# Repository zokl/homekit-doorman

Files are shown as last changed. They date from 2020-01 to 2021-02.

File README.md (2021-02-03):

# Doorman HomeKit System
System of a doorbell and smart lock integration into Apple HomeKit. The project platform is ESP8266 - [WeMos D1 Mini](https://wiki.wemos.cc/products:d1:d1_mini). Target door phone system is [Fermax](https://github.com/zokl/homekit-doorman/blob/master/doc/Fermax%20CityMax%20Universal%20%20Intercom%20Handset%20Data%20Sheet.pdf).

The SW part of the project is based on https://github.com/maximkulkin/esp-homekit-demo and https://github.com/pfalcon/esp-open-sdk.

## Fermax phone interconnection

Fermax phone signals:
* **RingDet** - ringing detector
   * **3** - common (- on PCB)
   * **4** - call (+ on PCB)
* **Lock** - door lock control
   * **1** - door opener and microphone supply (+ on PCB)
   * **3** - common (+ on PCB)

## Initial configuration

The initial configuration could be modified in the file [config.h](https://github.com/zokl/homekit-doorman/blob/master/src/config.h).

### HomeKit Access Parameters

* HOMEKIT_PASSWORD - "111-00-111"
* HOMEKIT_SETUP_ID - "1QJ9"

### System Parameters

* The GPIO pin that is connected to a relay - WeMos D1 Mini - Pin D1
* The GPIO pin that is connected to a LED - WeMos D1 Mini - Pin D4 (Internal Blue LED)
* The GPIO pin that is connected to a button - WeMos D1 Mini - Pin D3
  * Button for door open or factory reset
* The GPIO pin that is connected to a door bell - WeMos D1 Mini - Pin D2
  * Door bell detection - iOS notify as moving
* Timeout in seconds to open lock for - 5 seconds
* Button timeout for log press - 10000 ms (factory reset)
  * Shorter press = open the door
* Doorbell notify timeout - 3000 ms
  * After this timeout system disarm the door bell notification

## PCB Design

PCB is designed for using in DIN rail box [Z103J ABS V0 KRADEX](https://github.com/zokl/homekit-doorman/blob/master/doc/dsh.627-099.1.pdf) with AC/DC power supply [MEAN WELL DR-15-5](https://github.com/zokl/homekit-doorman/blob/master/doc/dsh.751-263.1.pdf). **The system can be powered only by 5V DC!!!**

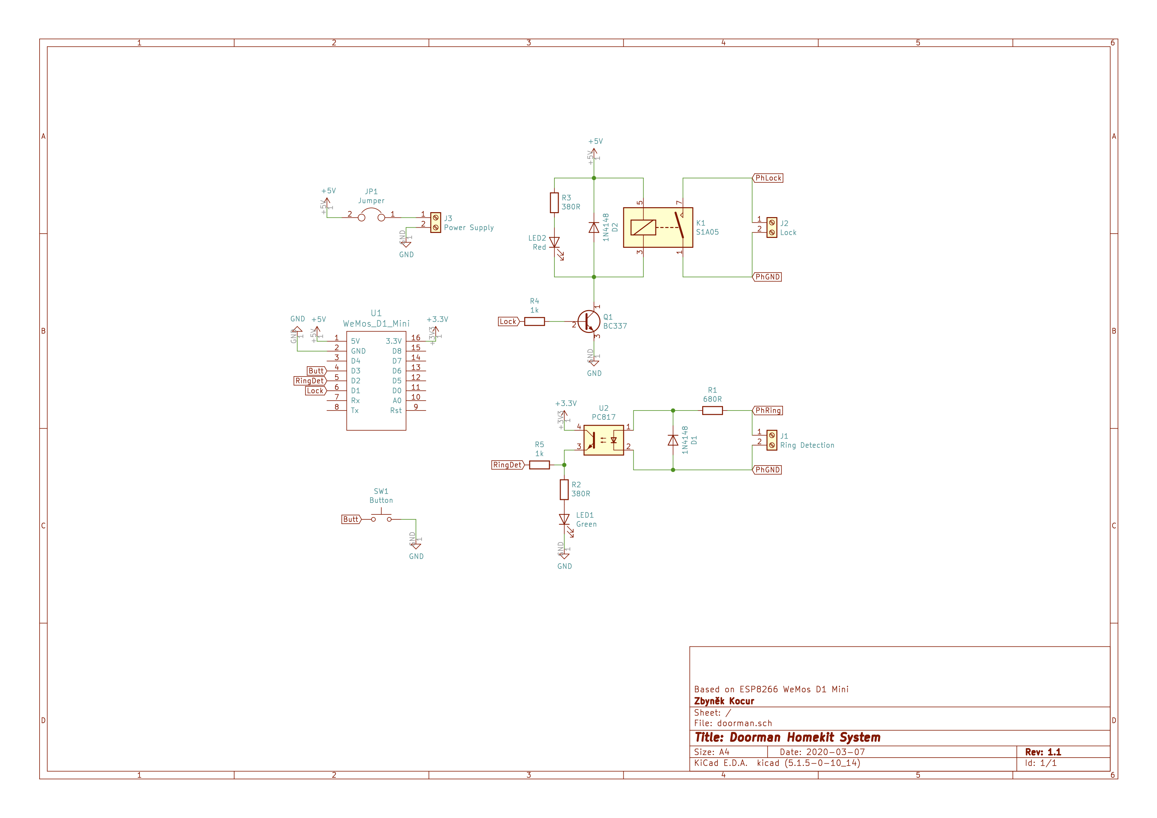
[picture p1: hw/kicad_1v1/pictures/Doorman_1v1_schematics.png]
Doorman v 1.1 - schematics


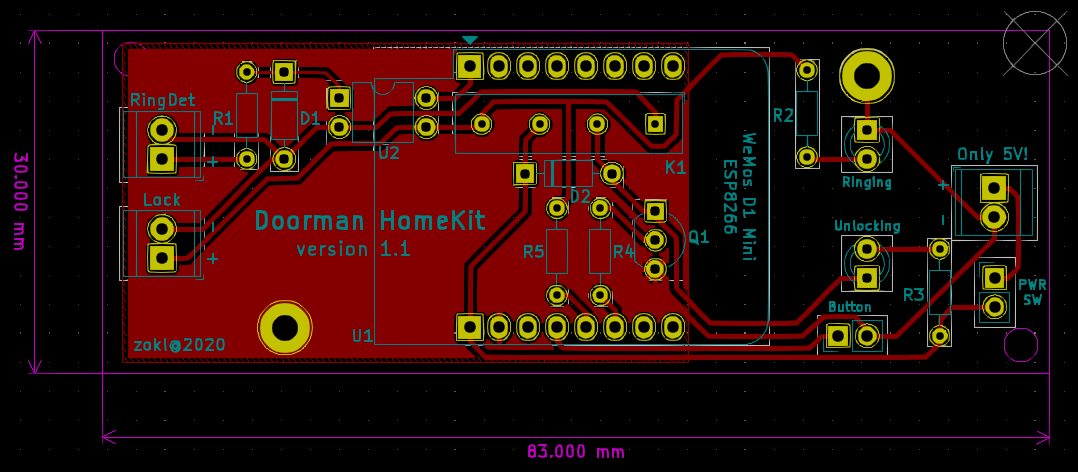
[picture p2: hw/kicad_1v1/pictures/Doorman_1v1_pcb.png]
Doorman v 1.1 - PCB


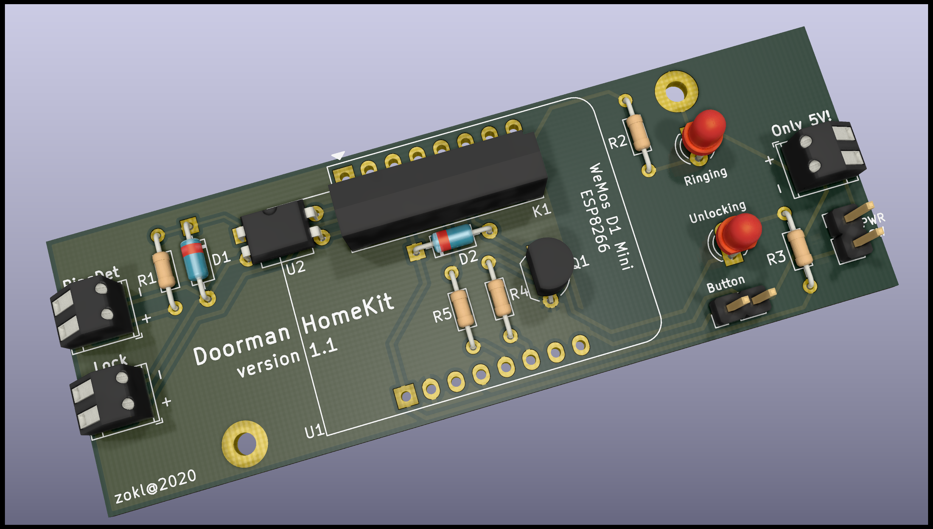
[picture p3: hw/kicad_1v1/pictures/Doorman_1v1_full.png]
Doorman v 1.1 - PCB render #1


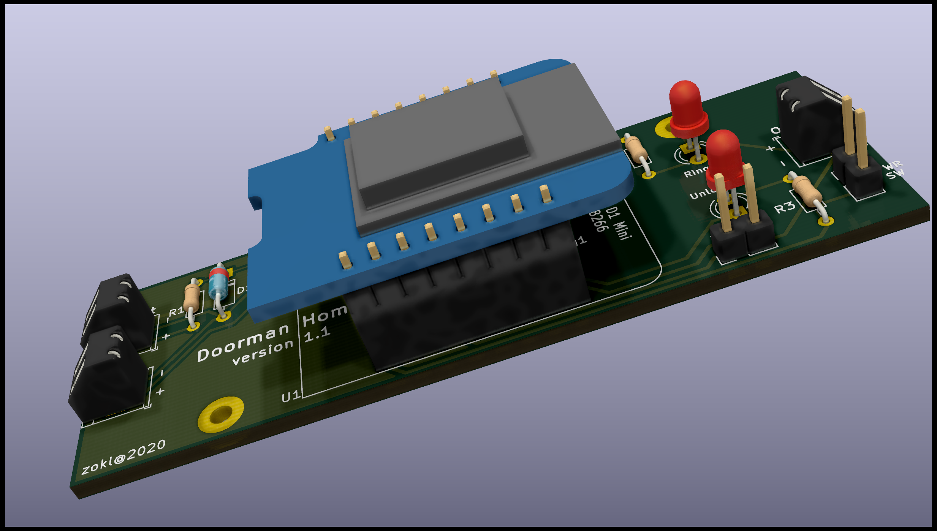
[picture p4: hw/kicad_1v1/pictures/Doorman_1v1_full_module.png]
Doorman v 1.1 - PCB render #1


## Compilation and deployment
All binary files are in ```bin``` directory.

### Flash process

```
esptool.py write_flash -fs 1MB -fm dout -ff 40m 0x0 rboot.bin 0x1000 blank_config.bin 0x2000 doorman.bin
```

* [rboot.bin](https://github.com/zokl/homekit-doorman/blob/master/bin/rboot.bin) - boot loader
* [blank_config.bin](https://github.com/zokl/homekit-doorman/blob/master/bin/blank_config.bin) - blank config partition
* [doorman.bin](https://github.com/zokl/homekit-doorman/blob/master/bin/doorman_20200307.bin) - firmware

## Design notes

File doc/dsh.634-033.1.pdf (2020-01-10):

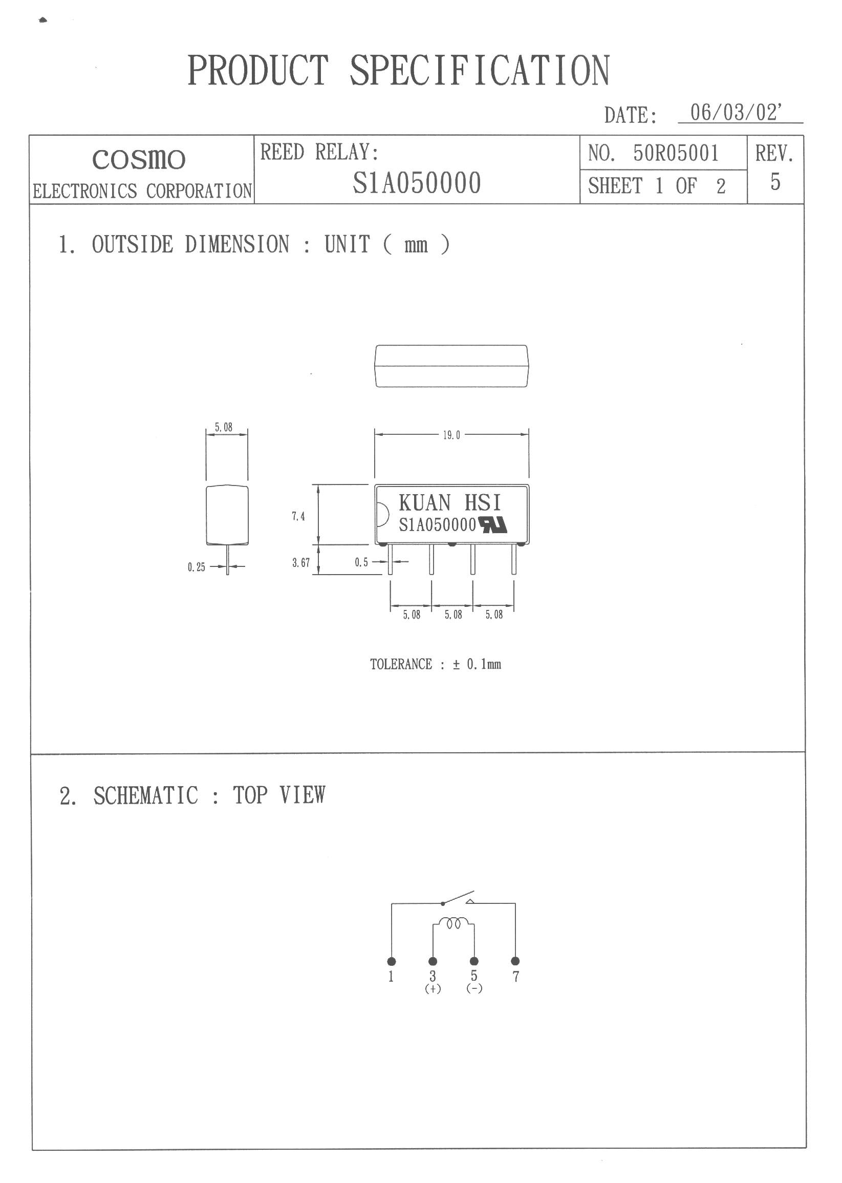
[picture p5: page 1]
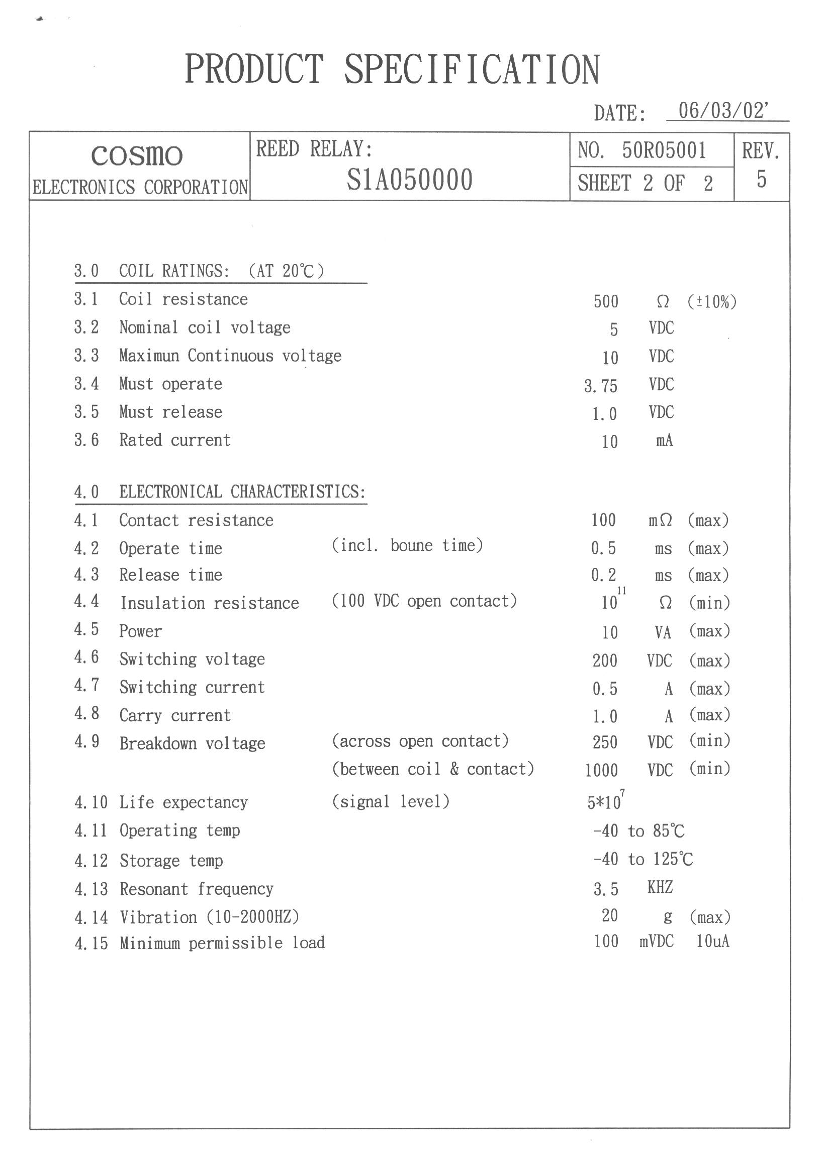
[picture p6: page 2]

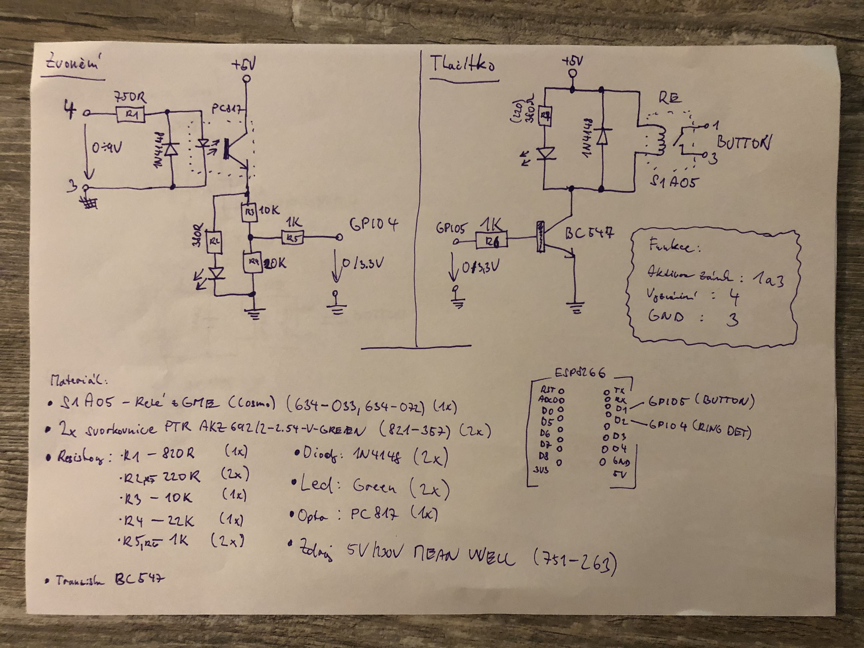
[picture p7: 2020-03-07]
doc/Dooropener_proposal.jpg

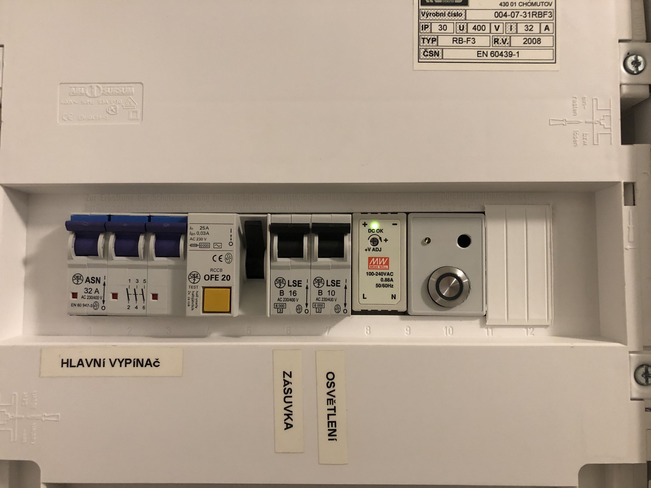
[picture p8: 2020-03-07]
foto/Rack_overview.jpg

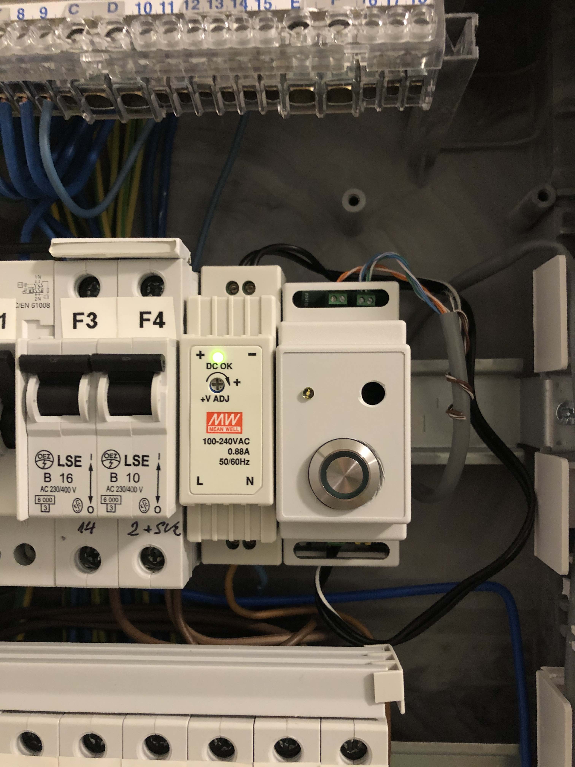
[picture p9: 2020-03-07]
foto/Rack_detail.jpg

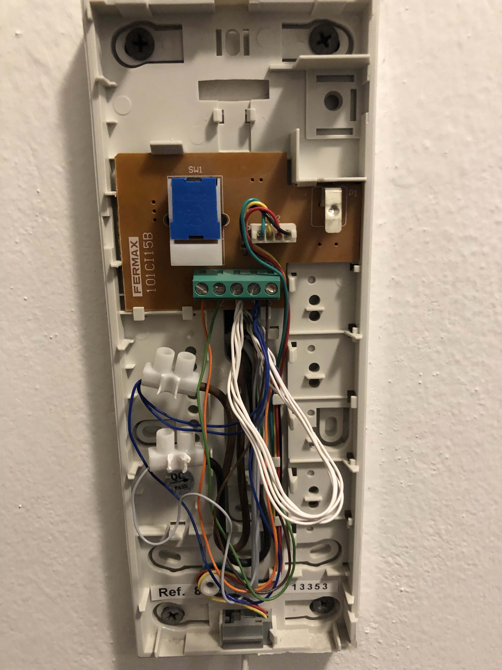
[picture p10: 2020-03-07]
foto/Door_phone.jpg

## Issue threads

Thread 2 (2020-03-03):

PCB layout problem

zokl, 2020-03-03:
Wrong WeMos D1 Mini PCB board layout used. ESP module is rotated by 180st and pins D1 and D3 are swapped.

Closed 2020-03-07.

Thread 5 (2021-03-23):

Fermax iloft 4+n

myrulezzz, 2021-03-23:
Hi i ve seen your project and looks interesting.As i understood you are using a fermax VDS monitor. I have a fermax iloft 4+n(analogue). Is this project compatible or is it only for vds technology?

zokl, 2021-03-27:
Hello, I use only a relay in parallel with the switch on phone. I think that this will be the same in your phone system.

Closed 2021-04-07.

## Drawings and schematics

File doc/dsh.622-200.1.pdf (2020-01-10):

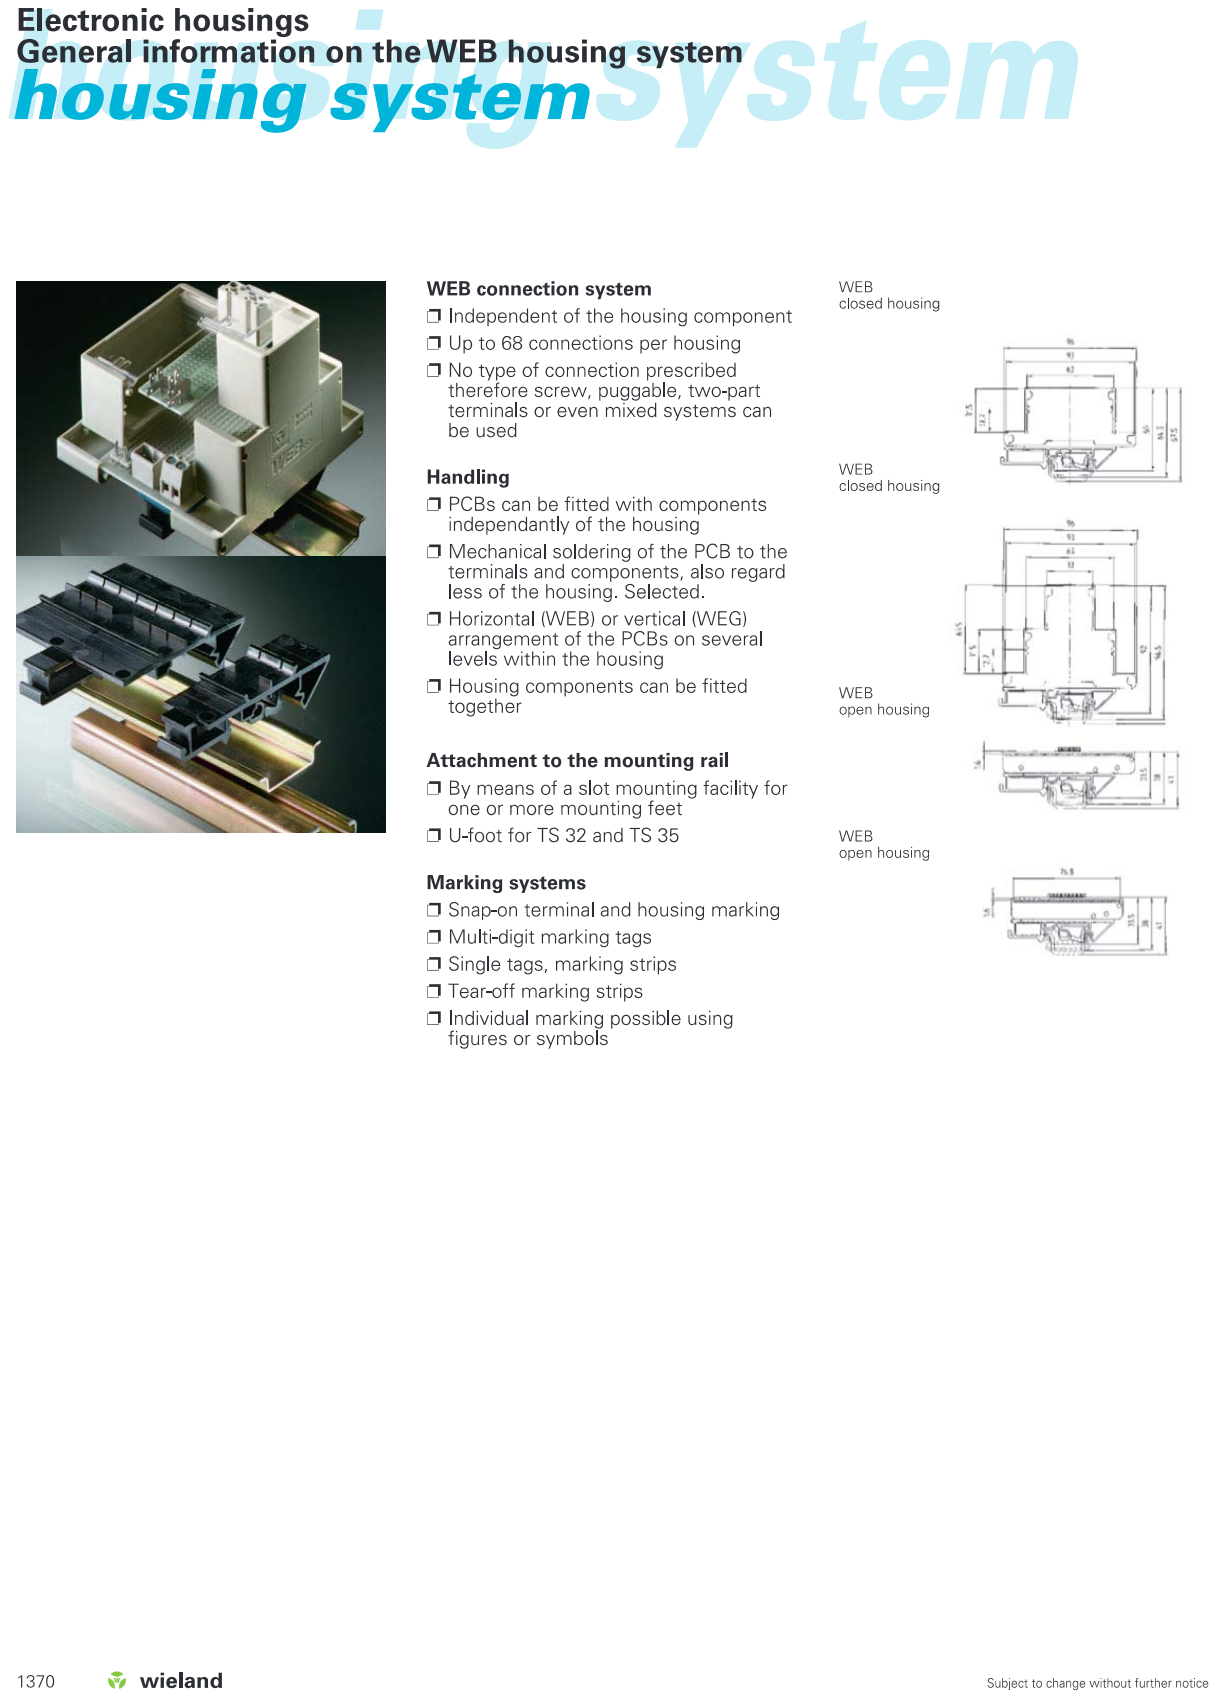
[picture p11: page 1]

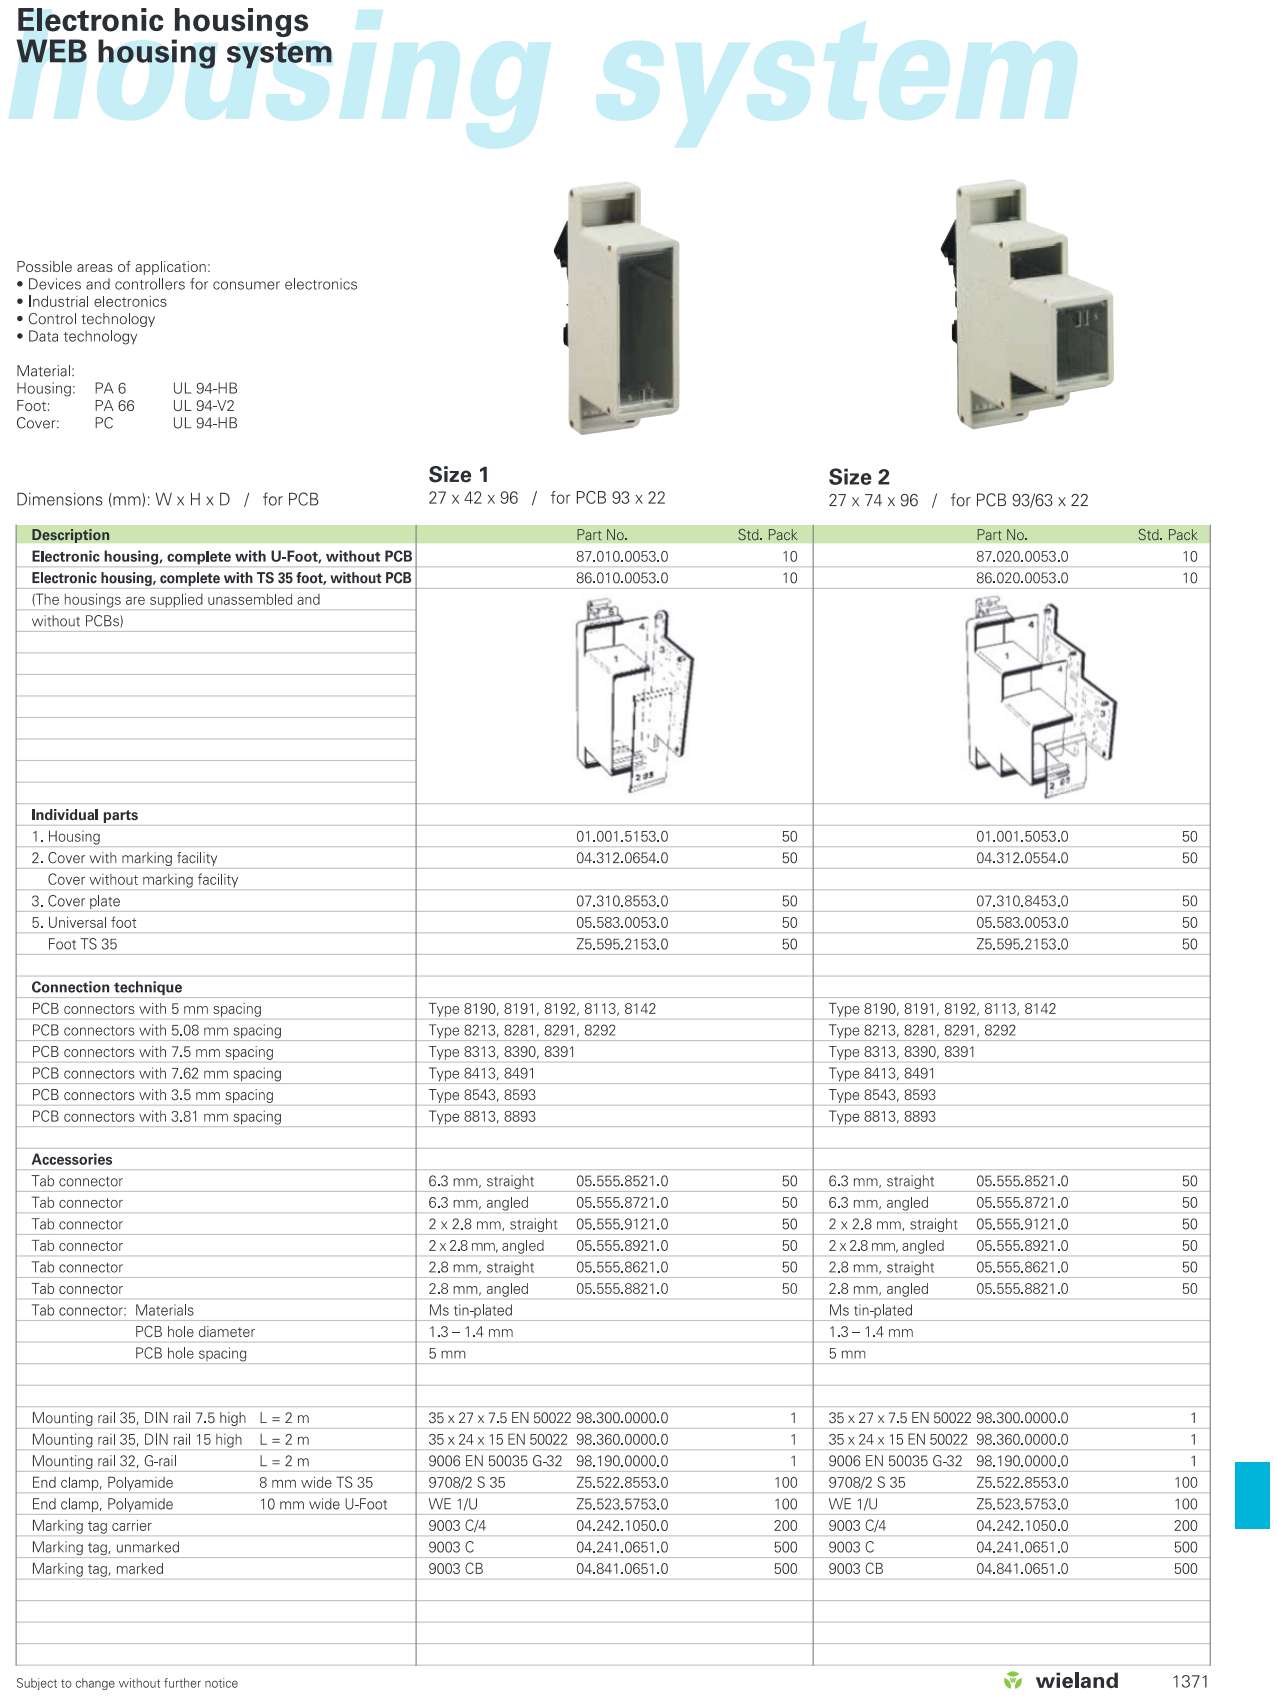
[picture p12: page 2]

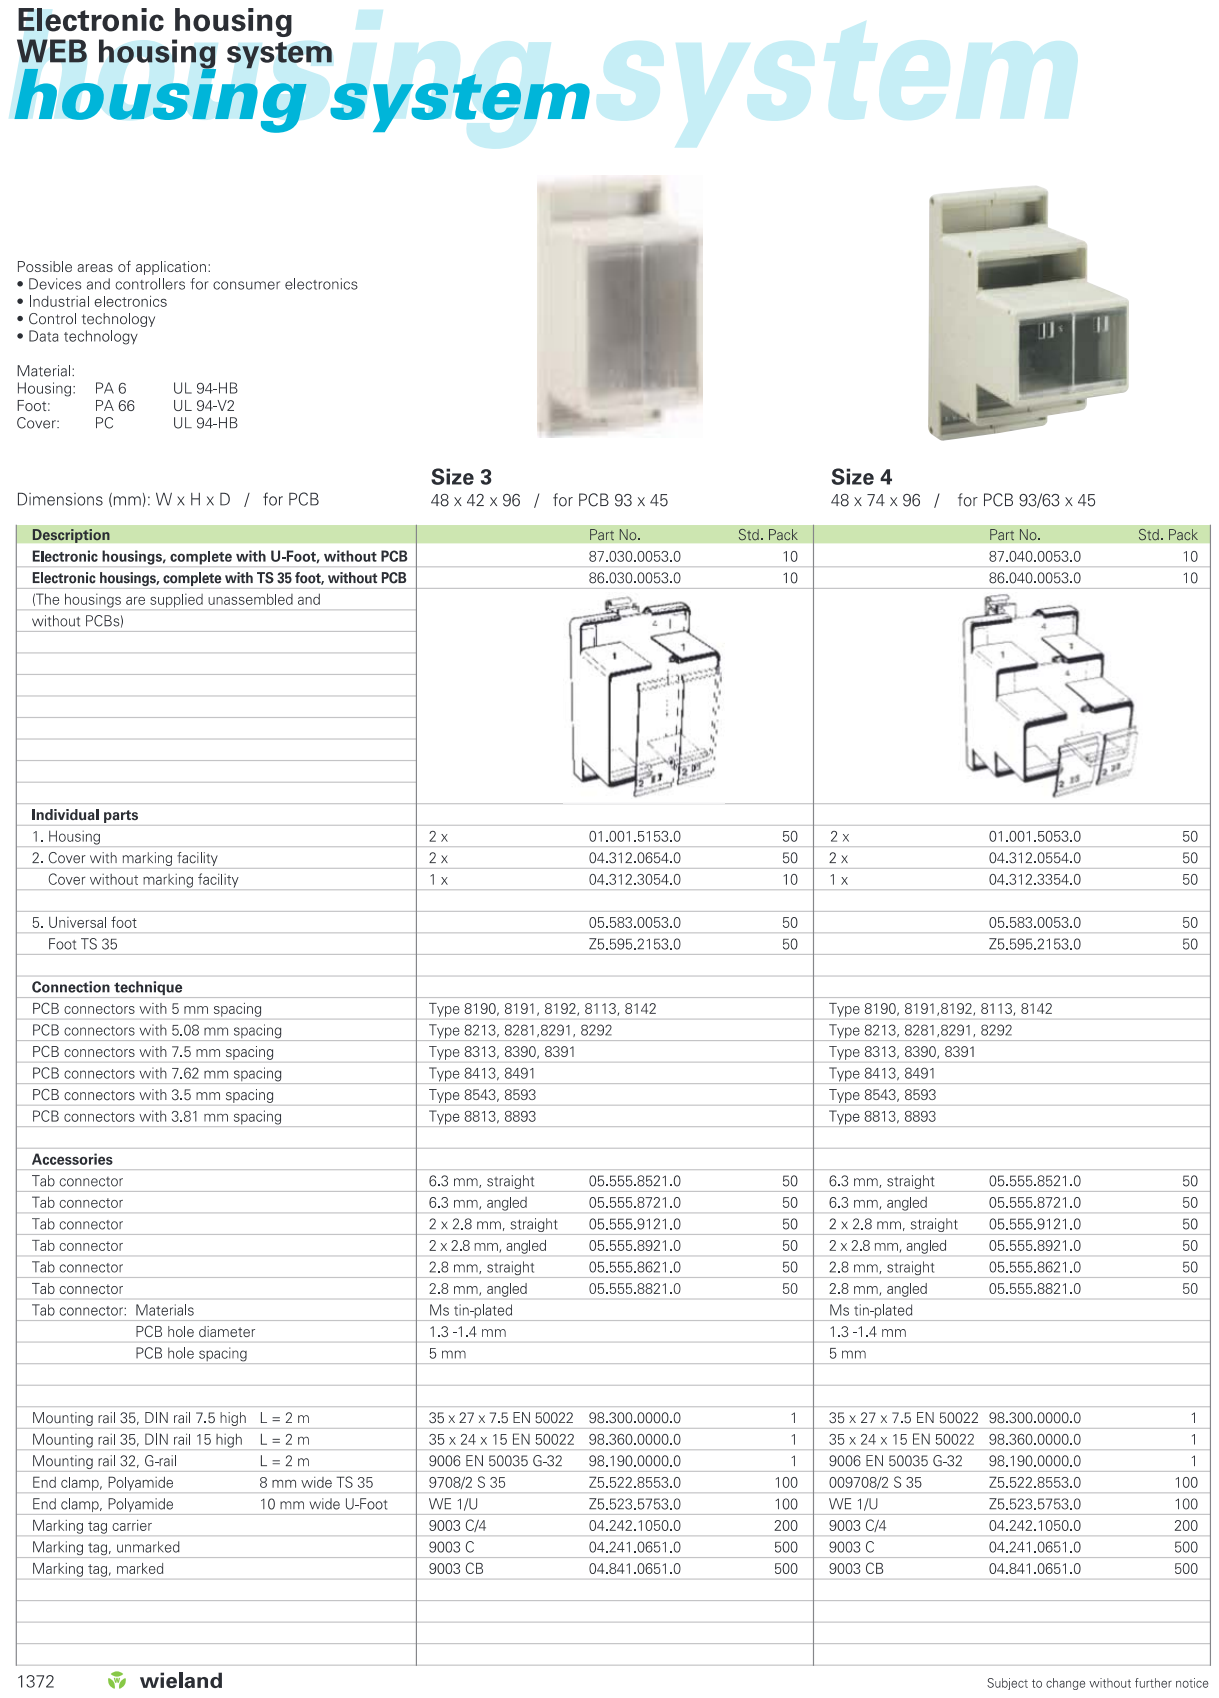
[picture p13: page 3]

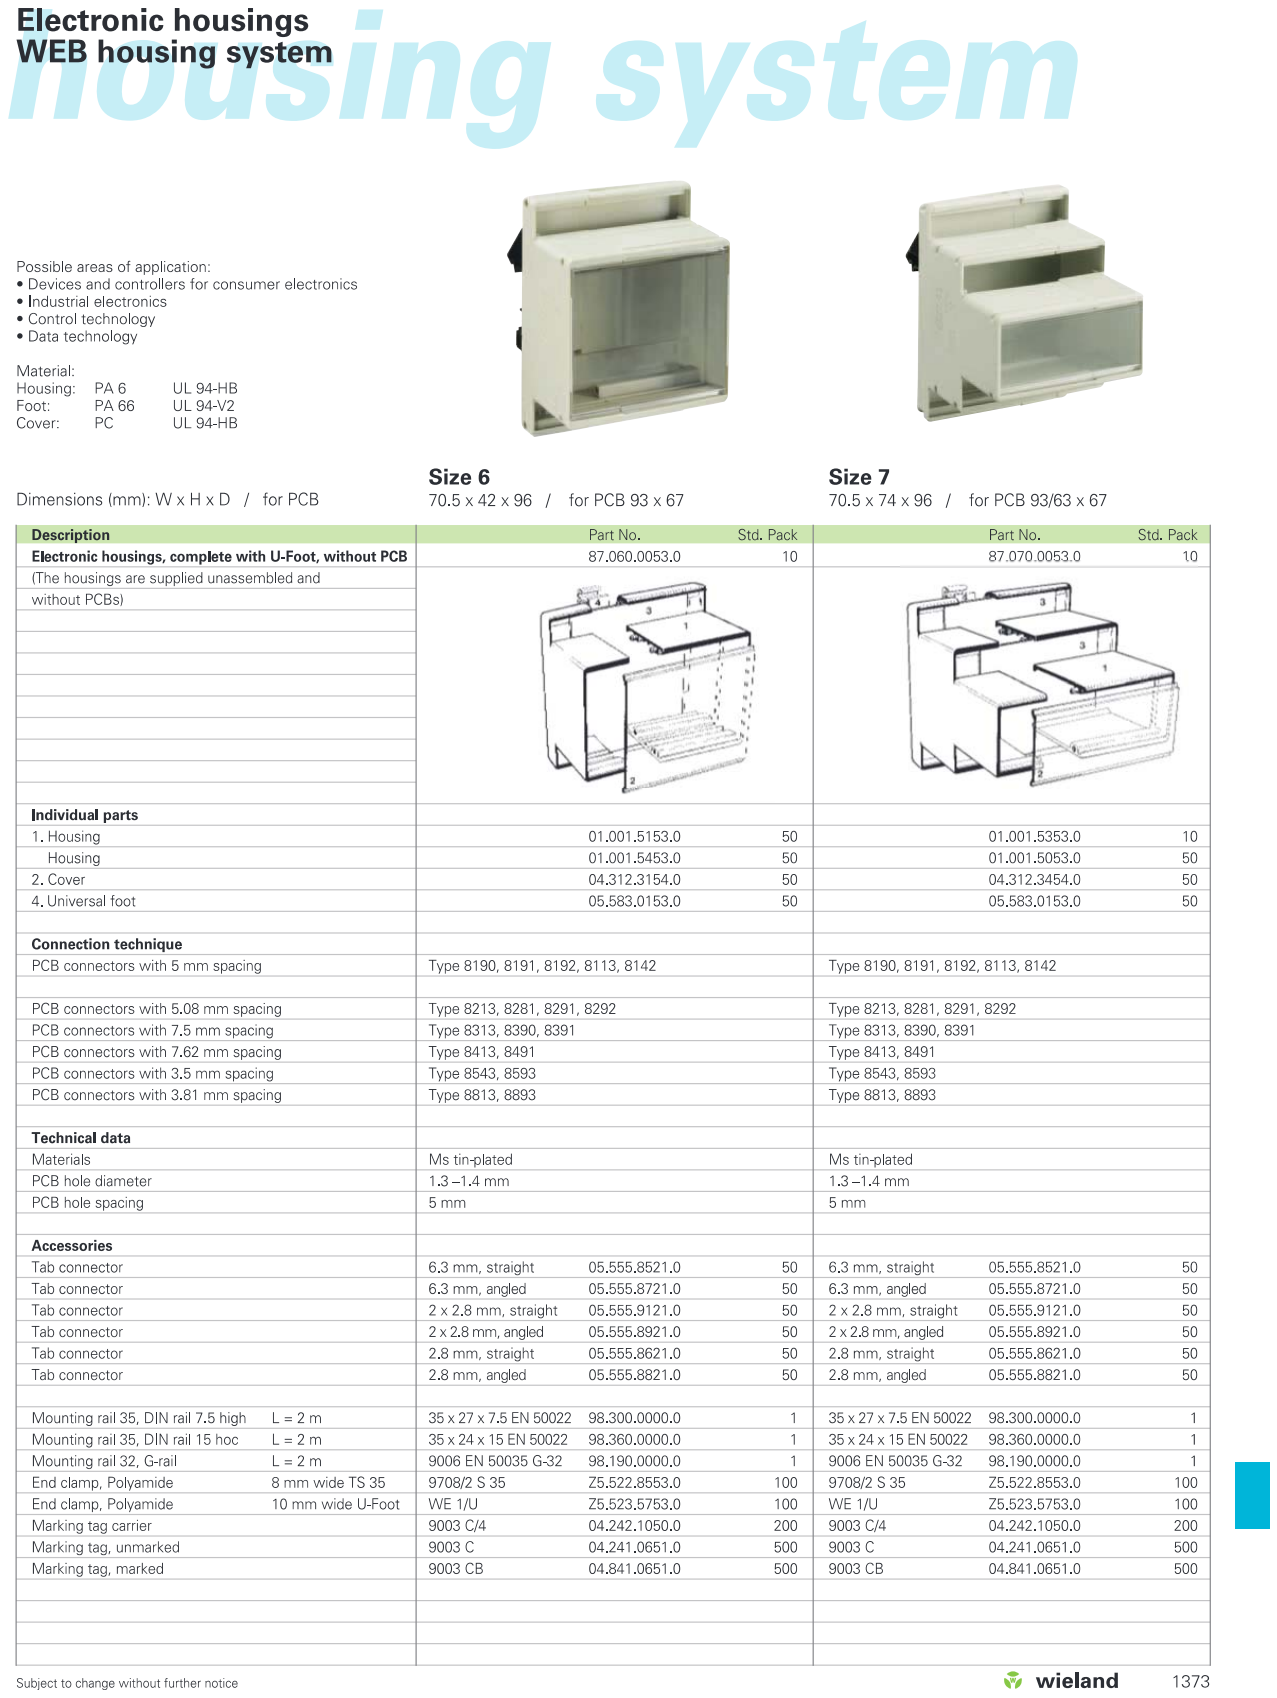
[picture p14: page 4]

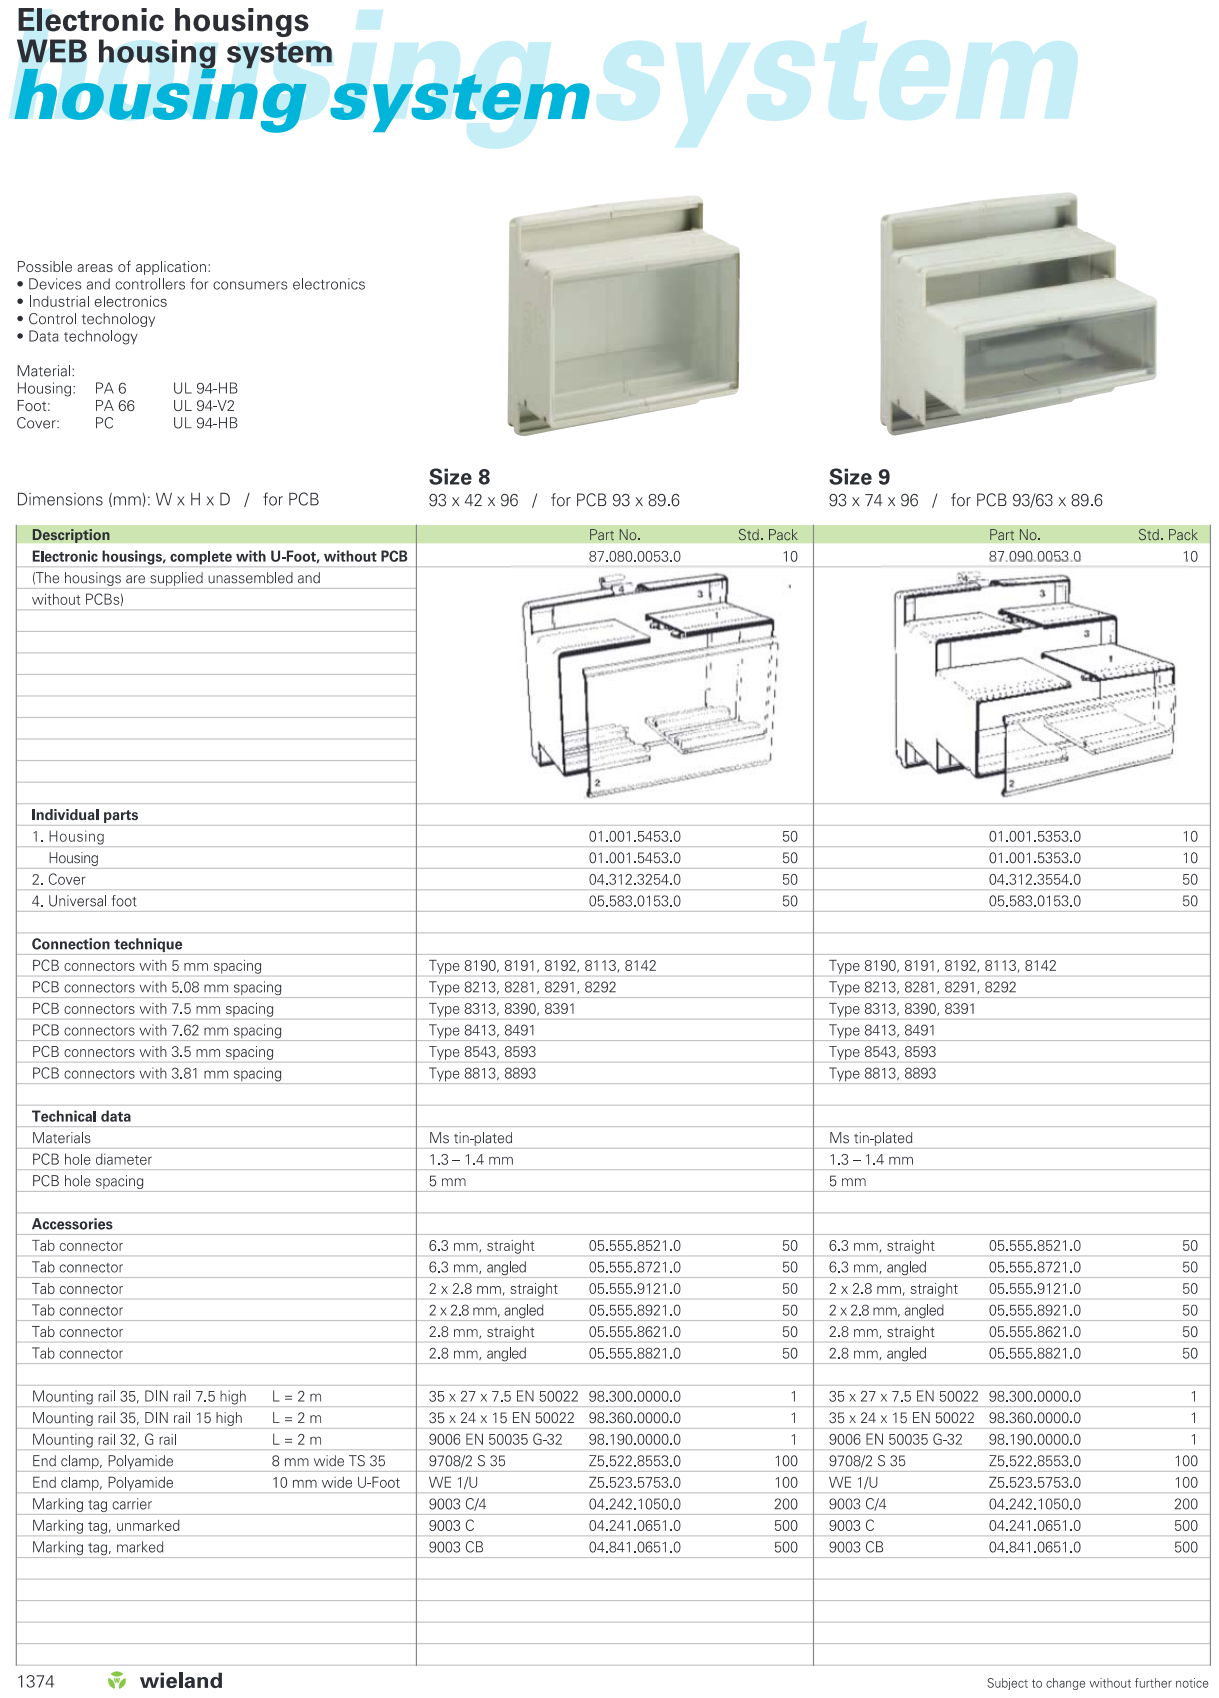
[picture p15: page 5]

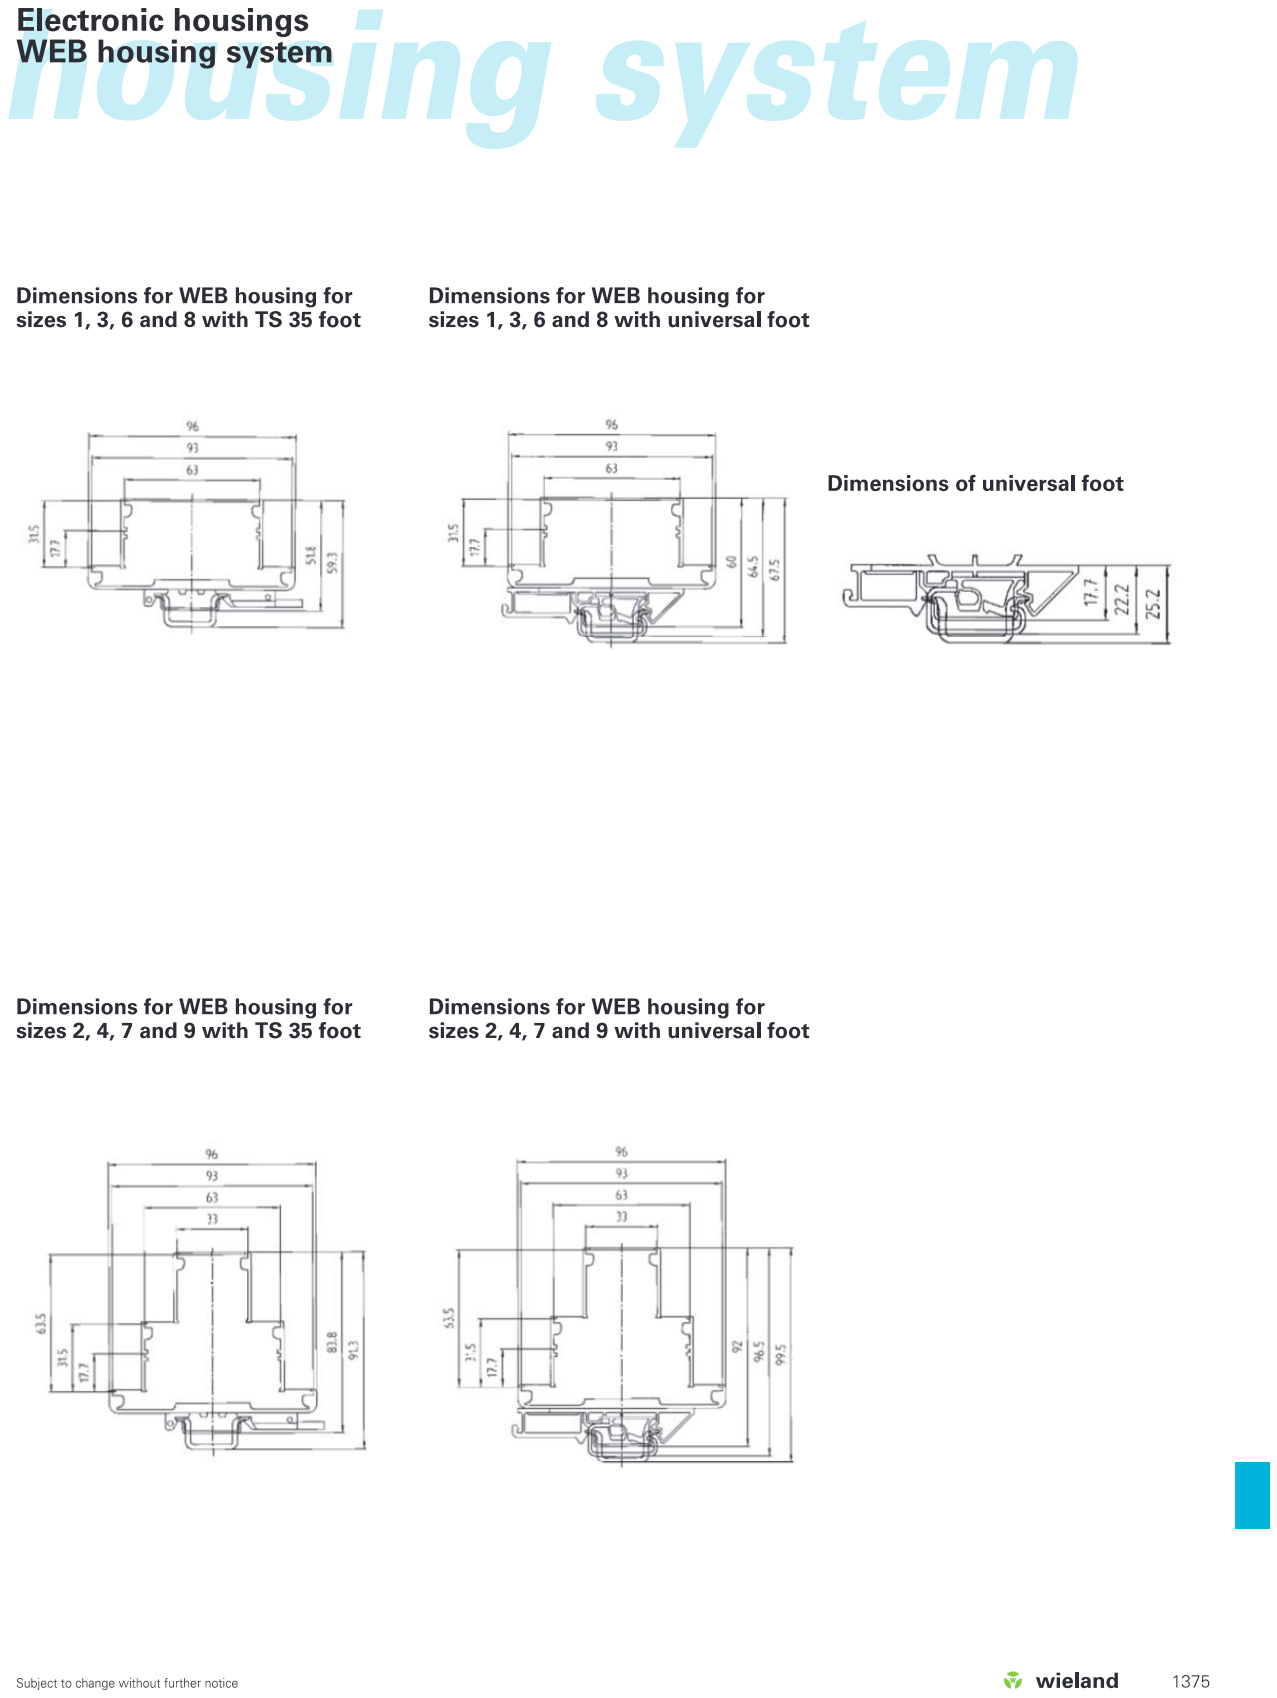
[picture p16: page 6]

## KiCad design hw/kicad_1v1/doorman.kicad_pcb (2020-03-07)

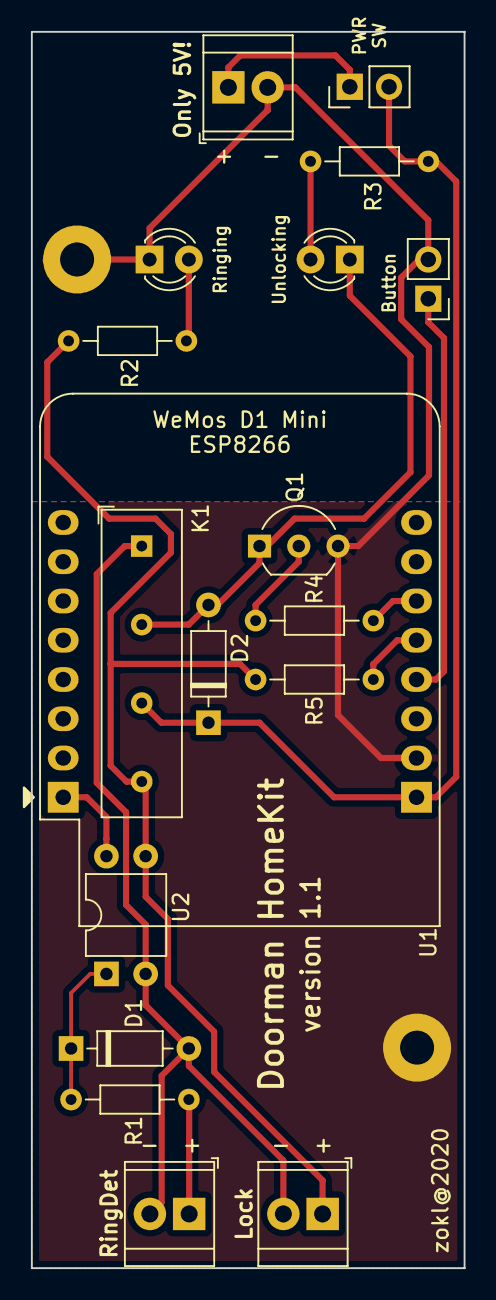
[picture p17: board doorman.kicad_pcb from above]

Board: 2 copper layers, 28.0 x 80.0 mm, 20 parts (0 on the bottom side), 15 nets.

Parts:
 : Jumper; PinHeader_1x02_P2.54mm_Vertical
Button: Button; PinHeader_1x02_P2.54mm_Vertical
D1, D2: 1N4148; D_DO-35_SOD27_P7.62mm_Horizontal
H1, H2: MountingHole_Pad; MountingHole_2.2mm_M2_Pad
J1: Ring Detection; TerminalBlock_TE_282834-2_1x02_P2.54mm_Horizontal
J2: Lock; TerminalBlock_TE_282834-2_1x02_P2.54mm_Horizontal
J3: Power Supply; TerminalBlock_TE_282834-2_1x02_P2.54mm_Horizontal
K1: S1A05; Relay_SPST_StandexMeder_SIL_Form1A
Q1: BC337; TO-92_Inline_Wide
R1: 680R; R_Axial_DIN0204_L3.6mm_D1.6mm_P7.62mm_Horizontal
R2, R3: 380R; R_Axial_DIN0204_L3.6mm_D1.6mm_P7.62mm_Horizontal
R4, R5: 1k; R_Axial_DIN0204_L3.6mm_D1.6mm_P7.62mm_Horizontal
Ringing: Green; LED_D3.0mm
U1: WeMos_mini; WEMOS_D1_mini_light
U2: PC817; DIP-4_W7.62mm
Unlocking: Red; LED_D3.0mm

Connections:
+3V3: U1.16, U2.4
+5V: .2, D2.1, K1.5, R3.2, U1.1
Butt: Button.1, U1.4
GND: Button.2, H1.1, H2.1, J3.2, Q1.3, Ringing.1, U1.2
Lock: R4.2, U1.6
unnamed: D1.1, R1.2, U2.1
unnamed: D2.2, K1.3, Q1.1, Unlocking.1
unnamed: .1, J3.1
unnamed: R2.1, Ringing.2
unnamed: R3.1, Unlocking.2
unnamed: Q1.2, R4.1
PhGND: D1.2, J1.2, J2.2, K1.1, U2.2
PhLock: J2.1, K1.7, R2.2, R5.1, U2.3
PhRing: J1.1, R1.1
RingDet: R5.2, U1.5

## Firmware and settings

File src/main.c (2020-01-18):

/*
 * Implemenetation of lock mechanism accessory for a magnet lock.
 * When unlocked, it changes relay state (unlocks) for configured period and then
 * changes it back.
 */

#include <stdio.h>
#include <espressif/esp_wifi.h>
#include <espressif/esp_sta.h>
#include <espressif/esp_common.h>
#include <esp/uart.h>
#include <esp8266.h>
#include <FreeRTOS.h>
#include <task.h>
#include <etstimer.h>
#include <esplibs/libmain.h>

#include <homekit/homekit.h>
#include <homekit/characteristics.h>
#include <wifi_config.h>

#include "config.h"
#include "button.h"
#include "contact_sensor.h"

uint16_t state_old = CONTACT_CLOSED;

void lock_lock();
void lock_unlock();

void relay_write(int value) {
    gpio_write(GPIO_RELAY, value ? 1 : 0);
}

void led_write(bool on) {
    gpio_write(GPIO_LED, on ? 0 : 1);
}

void show_config() {
    printf(">>> Initial config <<<\n");
    printf(">> Door Lock GPIO: %d\n", GPIO_RELAY);
    printf(">> Led GPIO: %d\n", GPIO_LED);
    printf(">> Unlock period: %d s\n", UNLOCK_PERIOD);
    printf(">> ------------------------------------------\n");
    printf(">> Button GPIO: %d\n", GPIO_BUTTON);
    printf(">> Button long press timeout %d ms\n", BUTTON_LONG_PRESS_TIMEOUT);
    printf(">> Button bounced time: %d ms\n", BUTTON_DEBOUNCED_TIME);
    printf(">> ------------------------------------------\n");
    printf(">> Doorbell GPIO: %d\n", GPIO_BELL);
    printf(">> Doorbell bounced interval: %d ms\n", DOORBELL_DEBOUNCED_TIME);
    printf(">> ------------------------------------------\n");
    printf(">> HomeKit setup id: %s\n", HOMEKIT_SETUP_ID);
    printf(">> HomeKit password: %s\n", HOMEKIT_PASSWORD);
    printf(">> ------------------------------------------\n\n");
}

void reset_configuration_task() {
    //Flash the LED first before we start the reset
    for (int i=0; i<3; i++) {
        led_write(true);
        vTaskDelay(100 / portTICK_PERIOD_MS);
        led_write(false);
        vTaskDelay(100 / portTICK_PERIOD_MS);
    }

    printf("> Resetting Wifi Config\n");

    wifi_config_reset();

    vTaskDelay(1000 / portTICK_PERIOD_MS);

    printf("> Resetting HomeKit Config\n");

    homekit_server_reset();

    vTaskDelay(1000 / portTICK_PERIOD_MS);

    printf("> Restarting\n");

    sdk_system_restart();

    vTaskDelete(NULL);
}

void reset_configuration() {
    printf("> Resetting configuration\n");
    xTaskCreate(reset_configuration_task, "Reset configuration", 256, NULL, 2, NULL);
}

void gpio_init() {
    gpio_enable(GPIO_LED, GPIO_OUTPUT);
    led_write(false);

    gpio_enable(GPIO_RELAY, GPIO_OUTPUT);
    relay_write(!RELAY_OPEN_SIGNAL);
}

void button_callback(uint8_t gpio, button_event_t event) {
    switch (event) {
        case button_event_single_press:
            printf(">> Toggling relay <<\n");
            lock_unlock();
            break;
        case button_event_long_press:
            printf(">> Reset configuration !!!\n");
            reset_configuration();
            break;
        default:
            printf(">> Unknown button event: %d\n", event);
    }
}

void lock_identify_task(void *_args) {
    // We identify the device by Flashing it's LED.
    for (int i=0; i<3; i++) {
        for (int j=0; j<2; j++) {
            led_write(true);
            vTaskDelay(100 / portTICK_PERIOD_MS);
            led_write(false);
            vTaskDelay(100 / portTICK_PERIOD_MS);
        }

        vTaskDelay(250 / portTICK_PERIOD_MS);
    }

    led_write(false);

    vTaskDelete(NULL);
}

void lock_identify(homekit_value_t _value) {
    printf("> Lock identify\n");
    xTaskCreate(lock_identify_task, "Lock identify", 128, NULL, 2, NULL);
}

void doorbell_identify(homekit_value_t _value) {
    printf("> Bell identify\n");
    xTaskCreate(lock_identify_task, "Lock identify", 128, NULL, 2, NULL);
}

typedef enum {
    lock_state_unsecured = 0,
    lock_state_secured = 1,
    lock_state_jammed = 2,
    lock_state_unknown = 3,
} lock_state_t;

homekit_characteristic_t name = HOMEKIT_CHARACTERISTIC_(NAME, "Doorman");

homekit_characteristic_t lock_current_state = HOMEKIT_CHARACTERISTIC_(
    LOCK_CURRENT_STATE,
    lock_state_unknown,
);

void lock_target_state_setter(homekit_value_t value);

homekit_characteristic_t lock_target_state = HOMEKIT_CHARACTERISTIC_(
    LOCK_TARGET_STATE,
    lock_state_secured,
    .setter=lock_target_state_setter,
);

void lock_target_state_setter(homekit_value_t value) {
    lock_target_state.value = value;

    if (value.int_value == 0) {
        lock_unlock();
    } else {
        lock_lock();
    }
}

void lock_control_point(homekit_value_t value) {
    // Nothing to do here
}

/**
 * Returns the bell state as a homekit value.
 **/
homekit_value_t doorbell_state_getter() {
    // printf(">> Doorbell state was requested (%s).\n", contact_sensor_state_get(GPIO_BELL) == CONTACT_OPEN ? "ringing" : "silence");
    // return HOMEKIT_UINT8(contact_sensor_state_get(GPIO_BELL) == CONTACT_OPEN ? 1 : 0);
    return HOMEKIT_BOOL(contact_sensor_state_get(GPIO_BELL) == CONTACT_OPEN ? 1 : 0);
}

/**
 * The sensor characteristic as global variable.
 **/
// homekit_characteristic_t doorbell_push_characteristic = HOMEKIT_CHARACTERISTIC_(OCCUPANCY_DETECTED, 0);
homekit_characteristic_t doorbell_push_characteristic = HOMEKIT_CHARACTERISTIC_(MOTION_DETECTED, 0);

/**
 * Called (indirectly) from the interrupt handler to notify the client of a state change.
 **/
// void contact_sensor_callback(uint8_t gpio, contact_sensor_state_t state) {
//     switch (state) {
//         case CONTACT_OPEN:
//         case CONTACT_CLOSED:
//             led_write(true);
//             doorbell_push_characteristic.value = doorbell_state_getter();
//             printf(">> Pushing bell state '%s'.\n", state == CONTACT_OPEN ? "ringing" : "silence");
//             homekit_characteristic_notify(&doorbell_push_characteristic, doorbell_push_characteristic.value);
//             led_write(false);
//             break;
//         default:
//             printf(">> Unknown bell event: %d\n", state);
//     }
// }

ETSTimer bell_timer;

void contact_sensor_callback(uint8_t gpio, contact_sensor_state_t state) {
    switch (state) {
        case CONTACT_OPEN:
        case CONTACT_CLOSED:
            led_write(true);
            doorbell_push_characteristic.value = doorbell_state_getter();
            // If doorbell on, start timeout for DOORBELL_OFF_DELAY, after expiration set force homekit notify to off.
            if (state == CONTACT_OPEN && state_old == CONTACT_CLOSED) {
                printf("Doorbell ringing !!!\n");
                homekit_characteristic_notify(&doorbell_push_characteristic, doorbell_push_characteristic.value);
                printf("Doorbell off delay timer for %d ms is starting ... \n", DOORBELL_OFF_DELAY);
                sdk_os_timer_arm(&bell_timer, DOORBELL_OFF_DELAY, false);
                state_old  = CONTACT_OPEN;
            }
            led_write(false);
            break;
        default:
            printf(">> Unknown bell event: %d\n", state);
    }
}

ETSTimer lock_timer;

void lock_lock() {
    sdk_os_timer_disarm(&lock_timer);

    relay_write(!RELAY_OPEN_SIGNAL);
    led_write(false);

    if (lock_current_state.value.int_value != lock_state_secured) {
        lock_current_state.value = HOMEKIT_UINT8(lock_state_secured);
        homekit_characteristic_notify(&lock_current_state, lock_current_state.value);
    }
}

void lock_timeout() {
    if (lock_target_state.value.int_value != lock_state_secured) {
        lock_target_state.value = HOMEKIT_UINT8(lock_state_secured);
        homekit_characteristic_notify(&lock_target_state, lock_target_state.value);
    }

    lock_lock();
}

// Doorbell timeout callback
void doorbell_timeout() {
    printf("Forcing doorbell homekit notification off \n"); 
    sdk_os_timer_disarm(&bell_timer);
    homekit_characteristic_notify(&doorbell_push_characteristic, HOMEKIT_BOOL(CONTACT_CLOSED));
    state_old = CONTACT_CLOSED;
}

void lock_init() {
    lock_current_state.value = HOMEKIT_UINT8(lock_state_secured);
    homekit_characteristic_notify(&lock_current_state, lock_current_state.value);

    sdk_os_timer_disarm(&lock_timer);
    sdk_os_timer_setfn(&lock_timer, lock_timeout, NULL);

}

void  doorbell_init () {
    homekit_characteristic_notify(&doorbell_push_characteristic, doorbell_state_getter());

    sdk_os_timer_disarm(&bell_timer);
    sdk_os_timer_setfn(&bell_timer, doorbell_timeout, NULL);
}

void lock_unlock() {
    relay_write(RELAY_OPEN_SIGNAL);
    led_write(true);

    lock_current_state.value = HOMEKIT_UINT8(lock_state_unsecured);
    homekit_characteristic_notify(&lock_current_state, lock_current_state.value);

    if (UNLOCK_PERIOD) {
        sdk_os_timer_disarm(&lock_timer);
        sdk_os_timer_arm(&lock_timer, UNLOCK_PERIOD * 1000, 0);
    }
}

homekit_accessory_t *accessories[] = {
    HOMEKIT_ACCESSORY(.id=1, .category=homekit_accessory_category_door_lock, .services=(homekit_service_t*[]){
        HOMEKIT_SERVICE(ACCESSORY_INFORMATION, .characteristics=(homekit_characteristic_t*[]){
            &name,
            HOMEKIT_CHARACTERISTIC(MANUFACTURER, "zokl@2020"),
            // HOMEKIT_CHARACTERISTIC(SERIAL_NUMBER, "123456"),
            HOMEKIT_CHARACTERISTIC(MODEL, "Door Lock"),
            HOMEKIT_CHARACTERISTIC(FIRMWARE_REVISION, "1.0"),
            HOMEKIT_CHARACTERISTIC(IDENTIFY, lock_identify),
            NULL
        }),
        HOMEKIT_SERVICE(LOCK_MECHANISM, .primary=true, .characteristics=(homekit_characteristic_t*[]){
            HOMEKIT_CHARACTERISTIC(NAME, "Lock"),
            &lock_current_state,
            &lock_target_state,
            NULL
        }),
        HOMEKIT_SERVICE(LOCK_MANAGEMENT, .characteristics=(homekit_characteristic_t*[]){
            HOMEKIT_CHARACTERISTIC(LOCK_CONTROL_POINT, 
                .setter=lock_control_point
            ),
            HOMEKIT_CHARACTERISTIC(VERSION, "1"),
            NULL
        }),
        NULL
    }),

    HOMEKIT_ACCESSORY(.id=2, .category=homekit_accessory_category_switch, .services=(homekit_service_t*[]){
        HOMEKIT_SERVICE(ACCESSORY_INFORMATION, .characteristics=(homekit_characteristic_t*[]){
            // HOMEKIT_CHARACTERISTIC(NAME, "Home Bell"),
            HOMEKIT_CHARACTERISTIC(MANUFACTURER, "zokl@2020"),
            // HOMEKIT_CHARACTERISTIC(SERIAL_NUMBER, "0012346"),
            HOMEKIT_CHARACTERISTIC(MODEL, "Doorbell"),
            HOMEKIT_CHARACTERISTIC(FIRMWARE_REVISION, "1.0"),
            HOMEKIT_CHARACTERISTIC(IDENTIFY, doorbell_identify),
            NULL
        }),
        HOMEKIT_SERVICE(MOTION_SENSOR, .primary=true, .characteristics=(homekit_characteristic_t*[]){
            HOMEKIT_CHARACTERISTIC(NAME, "Doorbell"),
            &doorbell_push_characteristic,
            NULL
        }),
        NULL
    }),

    NULL
};

homekit_server_config_t config = {
    .accessories = accessories,
    .password = HOMEKIT_PASSWORD,
    .setupId = HOMEKIT_SETUP_ID,
};

void on_wifi_ready() {
    homekit_server_init(&config);
}

void create_accessory_name() {
    uint8_t macaddr[6];
    sdk_wifi_get_macaddr(STATION_IF, macaddr);

    int name_len = snprintf(NULL, 0, "Doorman-%02X%02X%02X",
                            macaddr[3], macaddr[4], macaddr[5]);
    char *name_value = malloc(name_len+1);
    snprintf(name_value, name_len+1, "Doorman-%02X%02X%02X",
             macaddr[3], macaddr[4], macaddr[5]);

    name.value = HOMEKIT_STRING(name_value);
}

void user_init(void) {
    uart_set_baud(0, 9600);
    show_config();
    create_accessory_name();

    wifi_config_init("doorman", NULL, on_wifi_ready);
    gpio_init();
    lock_init();
    doorbell_init();

    if (button_create(GPIO_BUTTON, BUTTON_PRESSED_EXPECTED_VALUE, BUTTON_LONG_PRESS_TIMEOUT, button_callback)) {
        printf("> Failed to initialize button\n");
    }

    if (contact_sensor_create(GPIO_BELL, contact_sensor_callback)) {
        printf("> Failed to initialize bell\n");
    }
}

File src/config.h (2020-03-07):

#pragma once

// The GPIO pin that is connected to a relay
#define GPIO_RELAY 5 // WeMos D1 Mini - Pin D1

// The GPIO pin that is connected to a LED
#define GPIO_LED 2 //WeMos D1 Mini - Pin D4 (Internal Blue LED)

// The GPIO pin that is connected to a button
// const int button_gpio = 0;
#define GPIO_BUTTON 0 // WeMos D1 Mini - Pin D3

// The GPIO pin that is connected to a door bell
// const int button_gpio = 4;
#define GPIO_BELL 4 // WeMos D1 Mini - Pin D2

// Timeout in seconds to open lock for
#define UNLOCK_PERIOD 5 // 5 seconds

// Which signal to send to relay to open the lock (0 or 1)
#define RELAY_OPEN_SIGNAL 1

// The expected value when the button is pressed. 
// For buttons connected to ground this is 0/false, 
// for other buttons this might be 1/true.
#define BUTTON_PRESSED_EXPECTED_VALUE 0

// Button timeout for log press in ms
#define BUTTON_LONG_PRESS_TIMEOUT 10000

// Button signal debounced time in ms
#define BUTTON_DEBOUNCED_TIME 50

// Doorbell signal debounced time in ms
#define DOORBELL_DEBOUNCED_TIME 20

// Doorbell notify timeout in ms
#define DOORBELL_OFF_DELAY 3000

#define HOMEKIT_PASSWORD "111-00-111"
#define HOMEKIT_SETUP_ID "1QJ9"

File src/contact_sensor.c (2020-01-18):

#include <string.h>
#include <etstimer.h>
#include <esplibs/libmain.h>
#include "contact_sensor.h"
#include "config.h"

typedef struct _contact_sensor {
    uint8_t gpio_num;
    contact_sensor_callback_fn callback;
    uint16_t debounce_time;
    uint32_t last_event_time;

    struct _contact_sensor *next;
} contact_sensor_t;


contact_sensor_t *sensors = NULL;


static contact_sensor_t *contact_sensor_find_by_gpio(const uint8_t gpio_num) {
    contact_sensor_t *sensor = sensors;
    while (sensor && sensor->gpio_num != gpio_num)
        sensor = sensor->next;

    return sensor;
}

contact_sensor_state_t contact_sensor_state_get(uint8_t gpio_num) {
    return gpio_read(gpio_num);
}


void contact_sensor_intr_callback(uint8_t gpio) {
    contact_sensor_t *sensor = contact_sensor_find_by_gpio(gpio);
    if (!sensor)
        return;

    uint32_t now = xTaskGetTickCountFromISR();
    if ((now - sensor->last_event_time) * portTICK_PERIOD_MS < sensor->debounce_time) {
        // debounce time, ignore events
        return;
    }
    sensor->last_event_time = now;

    sensor->callback(sensor->gpio_num, contact_sensor_state_get(sensor->gpio_num));    
}

int contact_sensor_create(const uint8_t gpio_num, contact_sensor_callback_fn callback) {
    contact_sensor_t *sensor = contact_sensor_find_by_gpio(gpio_num);
    if (sensor)
        return -1;

    sensor = malloc(sizeof(contact_sensor_t));
    memset(sensor, 0, sizeof(*sensor));
    sensor->gpio_num = gpio_num;
    sensor->callback = callback;

    sensor->next = sensors;
    sensors = sensor;

    uint32_t now = xTaskGetTickCountFromISR();
    sensor->last_event_time = now;

    // times in milliseconds
    sensor->debounce_time = DOORBELL_DEBOUNCED_TIME;

    //gpio_set_pullup(sensor->gpio_num, true, true);
    gpio_set_interrupt(sensor->gpio_num, GPIO_INTTYPE_EDGE_ANY, contact_sensor_intr_callback);

    return 0;
}


void contact_sensor_delete(const uint8_t gpio_num) {
    if (!sensors)
        return;

    contact_sensor_t *sensor = NULL;
    if (sensors->gpio_num == gpio_num) {
        // Skip first element:
        sensor = sensors;
        sensors = sensors->next;
    } else {
        contact_sensor_t *b = sensors;
        while (b->next) {
            if (b->next->gpio_num == gpio_num) {
                // Unlink middle element:
                sensor = b->next;
                b->next = b->next->next;
                break;
            }
        }
    }

    if (sensor) {
        gpio_set_interrupt(sensor->gpio_num, GPIO_INTTYPE_EDGE_ANY, NULL);
    }
}

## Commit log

2020-01-10 New device for doorbell.
2020-01-13 KiCAD PCB proposal.
    [doorman.kicad_pcb, doorman.sch]
2020-01-13 KiCAD PCB proposal.Minor description changes.
    [doorman.sch]
2020-01-15 New Dorman v 1.0 PCB design.
    [doorman.kicad_pcb, doorman.sch]
2020-01-15 PCB Update.
    [doorman.kicad_pcb]
2020-01-16 New PCB mask, new PWR wires size.
    [doorman.kicad_pcb]
2020-01-16 Final PCB.
    [doorman.kicad_pcb]
2020-01-16 PCB production documentation
    [doorman.kicad_pcb, doorman_pool.kicad_pcb]
2020-03-03 Fix the pin description.
    [config.h]
2020-03-03 First relase of redesign PCB because of wrong ESP module layout. Partialy fix #2
    [doorman.kicad_pcb, doorman.sch]
2020-03-07 New PCB layout. Version 1.1.
    Completly redesigned PCB layout. Fix of wrong Wemos D1 mini layout.
    New antenna position and connectors to external LEDs and BUTTON.
    [doorman.kicad_pcb, doorman.sch]
2020-03-07 Change directory structure.
    [doorman.kicad_pcb, doorman.sch]
2020-03-07 Change description layout. Add cotas.
    [doorman.kicad_pcb]
2020-03-07 Doorman v 1.1 PCB renders.
2020-03-07 Small changes
    - Add schematics picture.
    - Small changes in schematics description.
    - Rename pictures.
